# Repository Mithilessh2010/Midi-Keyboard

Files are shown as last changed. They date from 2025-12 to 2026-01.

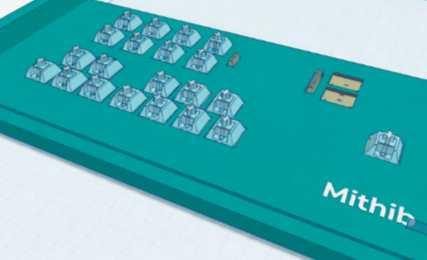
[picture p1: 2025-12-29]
Assets/CAD.png

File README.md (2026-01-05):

# Project README

## Overview
This project uses a Raspberry Pi Pico along with several input and output components to create a custom electronics system. The system includes switches, rotary encoders, a slide potentiometer, and supporting parts like diodes and connectors. The goal is to read user inputs and process them using the microcontroller.

## FINAL CAD WITH ASSEMBLED PARTS


## RENDER
Render

## SCHEMATICS
Schematics

## PCB
PCB

## CASE
CAD

## Bill of Materials (BOM)
| Component | Quantity | Price ($)  | Source |
| --- | --- | --- | --- |
| Cherry MX Blue Switch | 1 | 2.00 | [AliExpress](https://www.aliexpress.com/item/1005006255961111.html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) |
| Cherry MX Red Switch | 20 | 13.00 | [AliExpress](https://www.aliexpress.com/item/1005006255961111.html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) |
| S37735R Screen | 1 | N/A | Included in kit |
| 1N4148 Diode | 22 | N/A | Included in kit |
| Orpheus Pico | 1 | N/A | Included in kit |
| PCM5100 DAC | 1 | N/A | Included in kit |
| EC11 Rotary Encoder | 2 | N/A | Included in kit |
| M3 18 mm Screw | 4 | 1.06 | [BambuLab](https://us.store.bambulab.com/products/m3-button-head-cap-machine-screws-bhcs?id=42338644951176) |
| M3 4 mm Screw | 4 | 1.06 | [BambuLab](https://us.store.bambulab.com/products/m3-button-head-cap-machine-screws-bhcs?id=42338644721800) |
| M2 5 mm Screw | 2 | 1.02 | [BambuLab](https://us.store.bambulab.com/products/m2-button-head-cap-machine-screws-bhcs?id=42328200577160) |
| Slide Potentiometer | 1 | Included | [Adafruit](https://www.adafruit.com/product/4219) |
| ADS ADC Module | 1 | Included | [Adafruit](https://www.adafruit.com/product/1083) |
| **Adafruit Parts Total** | — | **34.30**  | [Adafruit](https://www.adafruit.com/) |
| **JLCPCB (PCB + Assembly)** | — | **52.46**  | [JLCPCB](https://jlcpcb.com/) |
| **BambuLab Shipping** | — | **6.00** | [BambuLab](https://us.store.bambulab.com/) |
| **TOTAL COST (All Parts)**  | — | **110.90** | — |

## How It Works
- The Raspberry Pi Pico acts as the main controller.
- Switches and encoders are used for user input.
- The slide potentiometer provides analog input.
- The ADC and DAC handle analog-to-digital and digital-to-analog conversion.
- Diodes help protect and control signal flow.

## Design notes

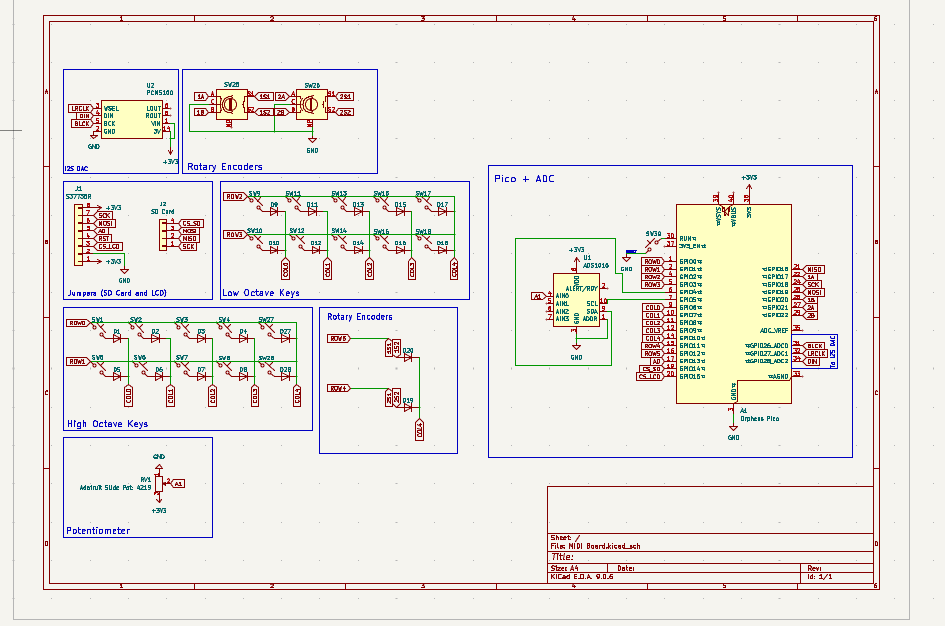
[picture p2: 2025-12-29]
Assets/Schematics.png

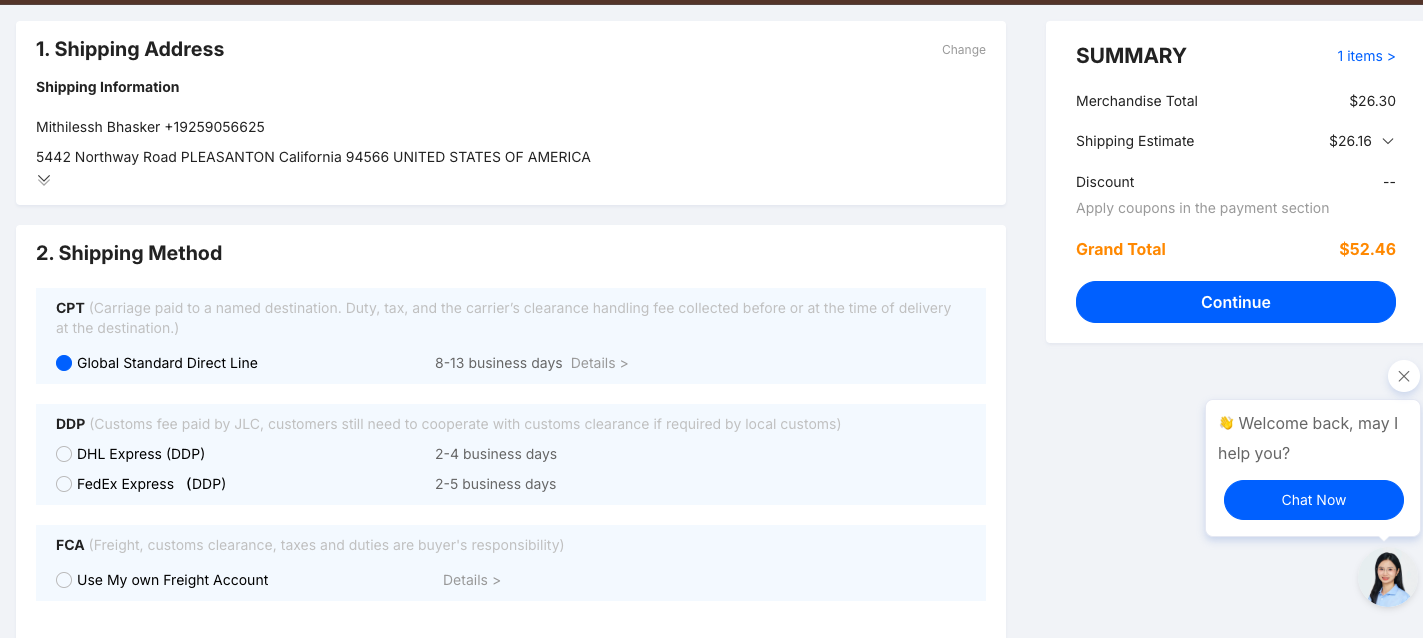
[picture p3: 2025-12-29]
Assets/JLCPCB.png

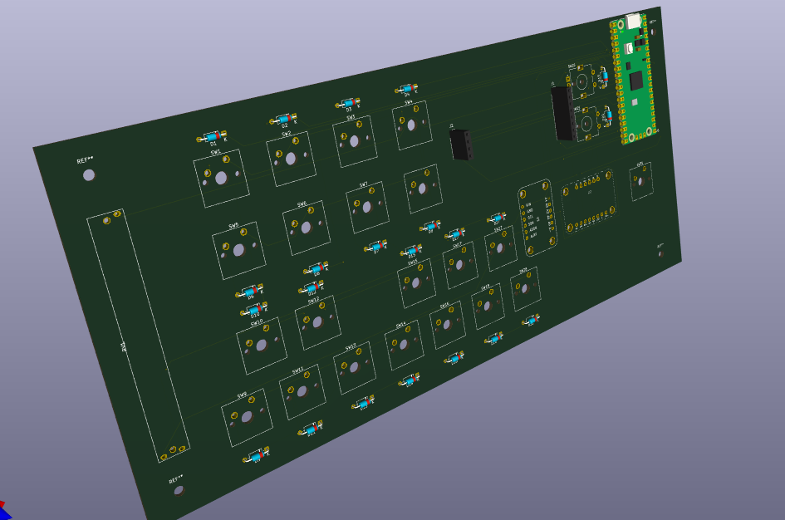
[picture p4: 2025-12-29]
Assets/Render.png

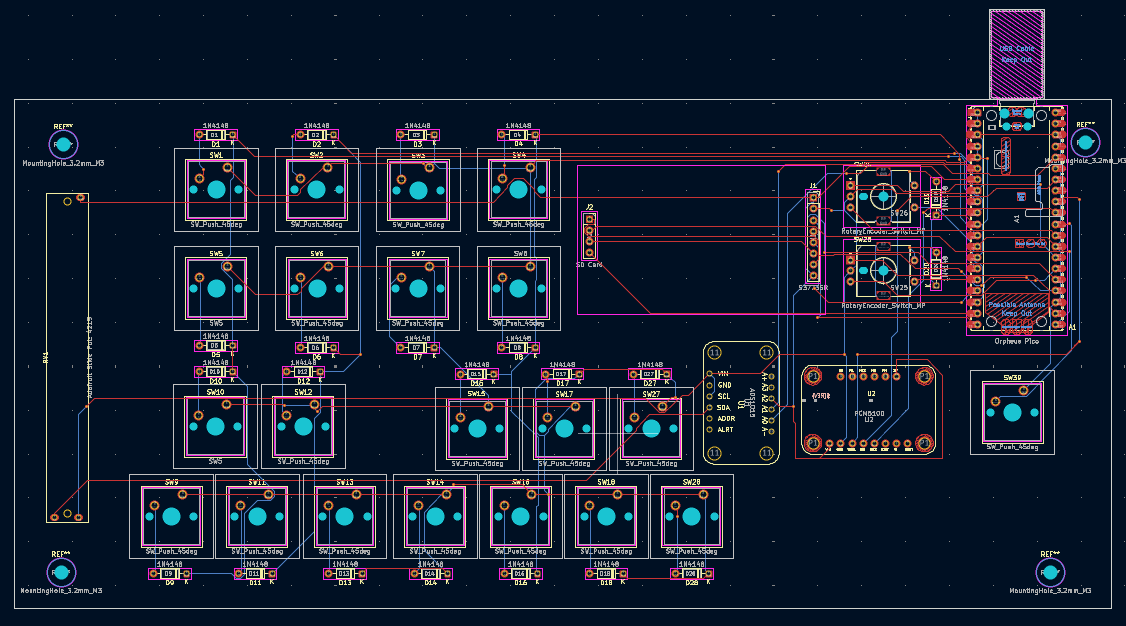
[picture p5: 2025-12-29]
Assets/PCB.png

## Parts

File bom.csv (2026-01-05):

Component | Quantity | Price ($) | Source
Cherry MX Blue Switch | 1 | 2.00 | https://www.aliexpress.com/item/1005006255961111.html?mp=1
Cherry MX Red Switch | 20 | 13.00 | https://www.aliexpress.com/item/1005006255961111.html?mp=1
S37735R Screen | 1 | N/A | Included in kit
1N4148 Diode | 22 | N/A | Included in kit
Orpheus Pico | 1 | N/A | Included in kit
PCM5100 DAC | 1 | N/A | Included in kit
EC11 Rotary Encoder | 2 | N/A | Included in kit
M3 18 mm Screw | 4 | 1.06 | https://us.store.bambulab.com/products/m3-button-head-cap-machine-screws-bhcs?id=42338644951176
M3 4 mm Screw | 4 | 1.06 | https://us.store.bambulab.com/products/m3-button-head-cap-machine-screws-bhcs?id=42338644721800
M2 5 mm Screw | 2 | 1.02 | https://us.store.bambulab.com/products/m2-button-head-cap-machine-screws-bhcs?id=42328200577160
Slide Potentiometer | 1 | Included | https://www.adafruit.com/product/4219
ADS ADC Module | 1 | Included | https://www.adafruit.com/product/1083
Adafruit Parts Total | — | 34.30 | https://www.adafruit.com/
JLCPCB (PCB + Assembly) | — | 52.46 | https://jlcpcb.com/
BambuLab Shipping | — | 6.00 | https://us.store.bambulab.com/
TOTAL COST (All Parts) | — | 110.90

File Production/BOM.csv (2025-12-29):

Id | Designator | Footprint | Quantity | Designation | Supplier and ref
1 | SW4,SW14,SW6,SW11,SW9,SW28,SW15,SW12,SW18,SW3,SW1,SW2,SW13,SW16,SW27,SW8,SW39,SW7,SW17 | SW_Cherry_MX_1.00u_PCB | 19 | SW_Push_45deg
2 | D7,D11,D6,D27,D2,D13,D1,D15,D20,D19,D17,D4,D16,D18,D5,D9,D3,D28,D14,D12,D8,D10 | D_DO-35_SOD27_P7.62mm_Horizontal | 22 | 1N4148
3 | J1 | PinSocket_1x08_P2.54mm_Vertical | 1 | S37735R
4 | SW10,SW5 | SW_Cherry_MX_1.00u_PCB | 2 | SW5
5 | U1 | Adafruit_ADS1115 | 1 | ADS1015
6 | SW25,SW26 | RotaryEncoder_Alps_EC11E-Switch_Vertical_H20mm_MountingHoles | 2 | RotaryEncoder_Switch_MP
7 | RV1 | Slide_Pot_75mm_Adafruit4219_fixed | 1 | Adafruit Slide Pot: 4219
8 | J2 | PinSocket_1x04_P2.54mm_Vertical | 1 | SD Card
9 | A1 | RaspberryPi_Pico_Common_Unspecified | 1 | Orpheus Pico
10 | U2 | PCM5100 I2S DAC | 1 | PCM5100

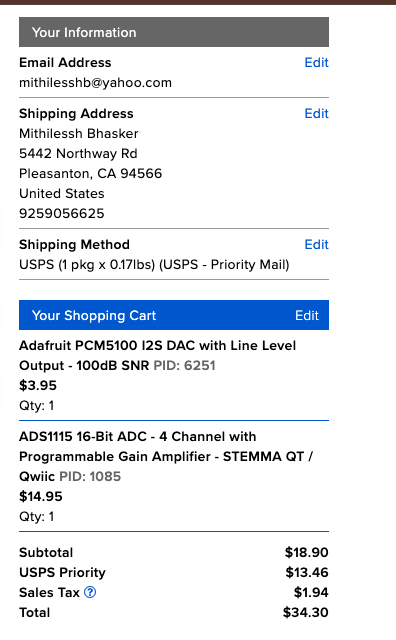
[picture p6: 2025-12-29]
Assets/Extra Parts Cost.png

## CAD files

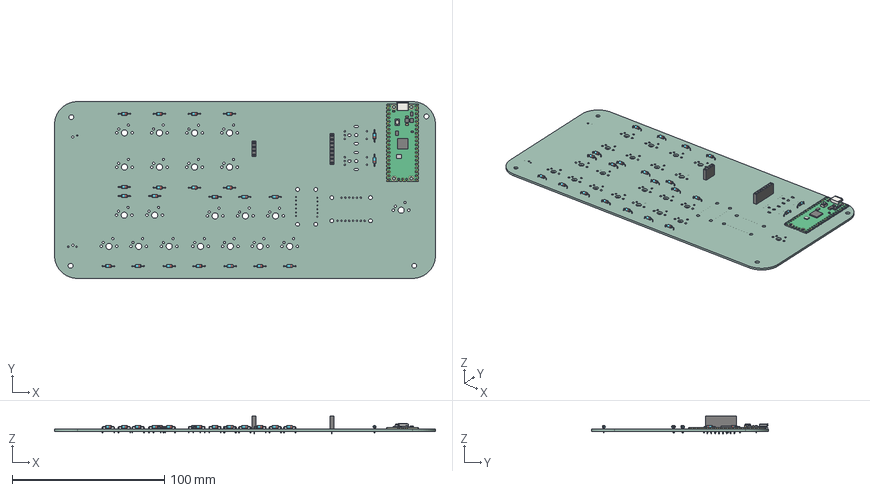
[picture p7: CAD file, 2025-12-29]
CAD/MIDI Board-PCB.step
250.0 x 116.0 x 11.6 mm
D_DO-35_SOD27_P7.62mm_Horizontal x 22
PinSocket_1x08_P2.54mm_Vertical
PinSocket_1x04_P2.54mm_Vertical
RaspberryPi_Pico_Module_KiCad
MIDI Board_PCB

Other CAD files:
CAD/pcb-with-case.stl

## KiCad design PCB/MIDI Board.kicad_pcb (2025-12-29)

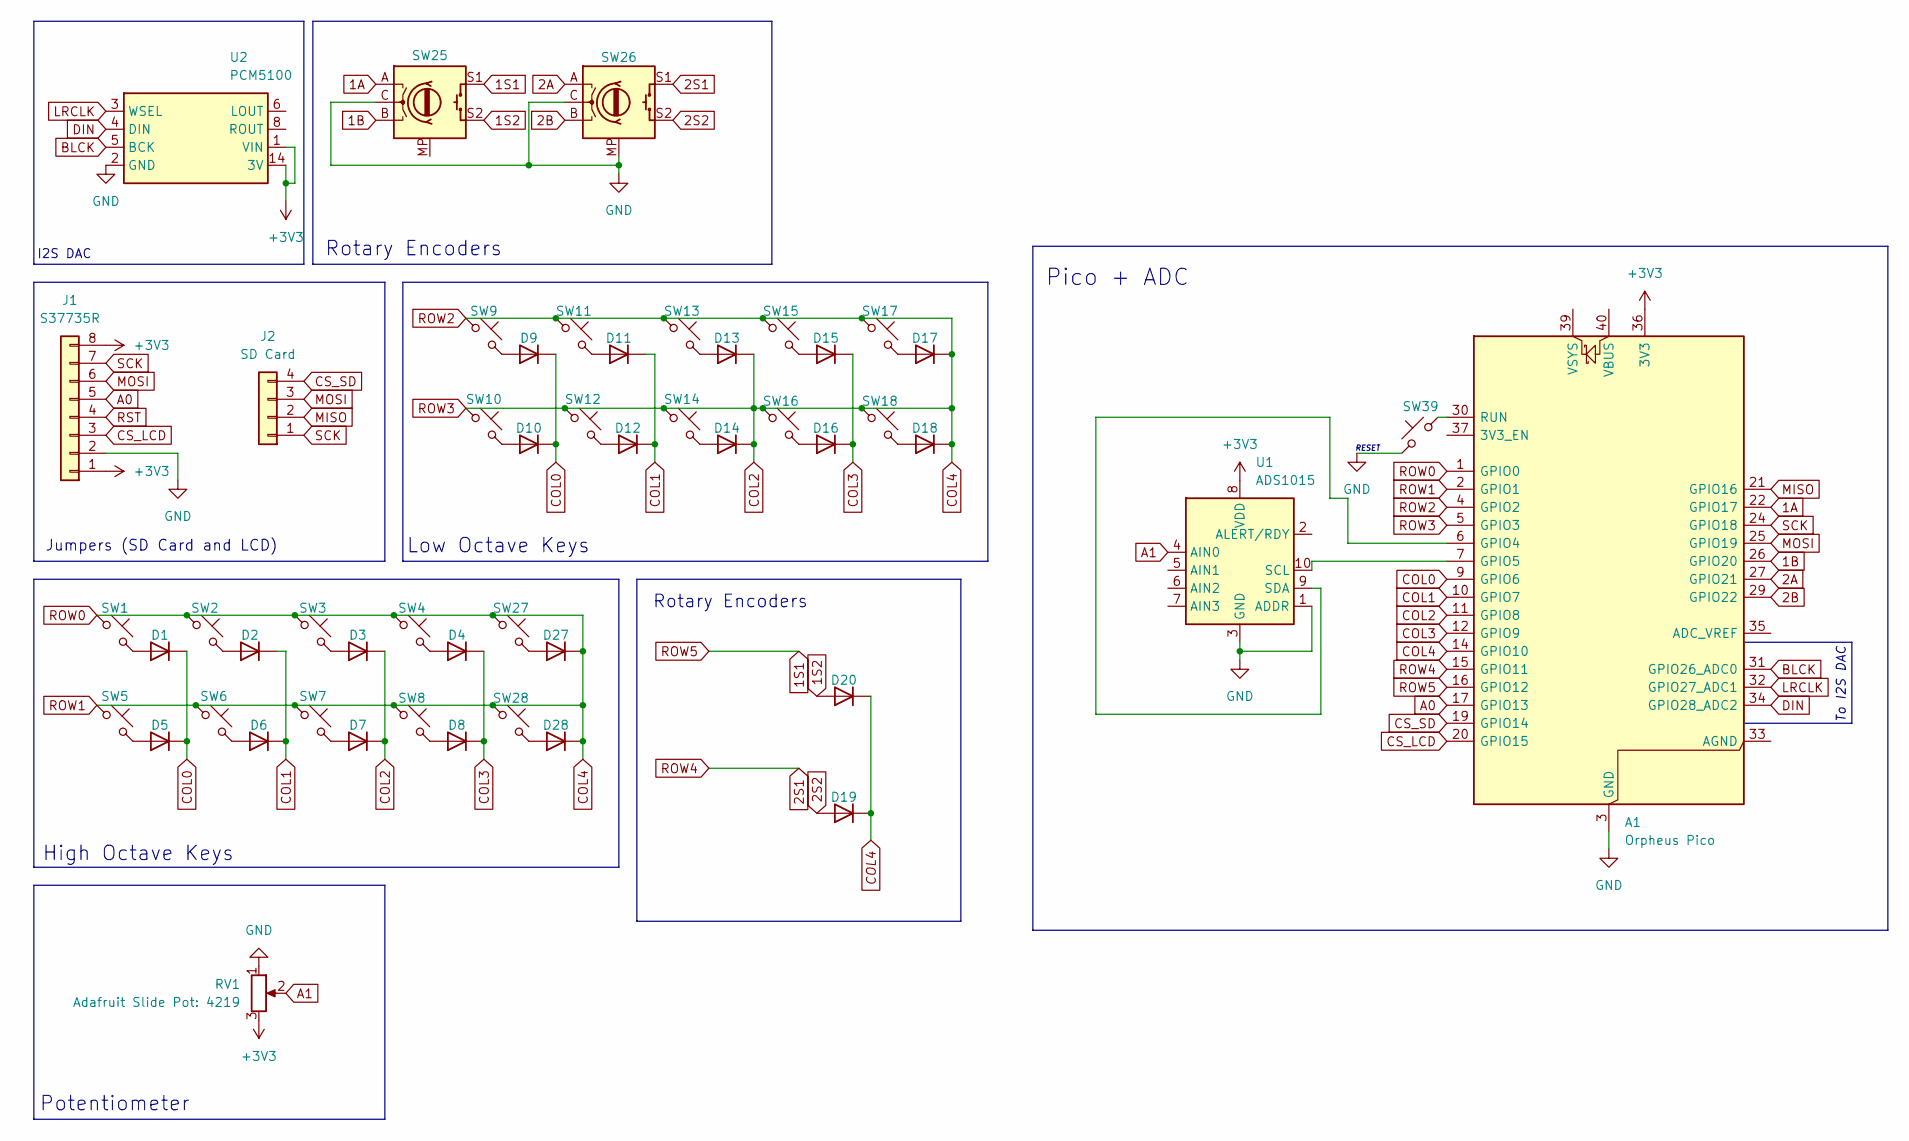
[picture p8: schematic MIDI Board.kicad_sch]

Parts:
A1: Orpheus Pico; RaspberryPi_Pico_Common_Unspecified
D1, D2, D3, D4, D5, D6, D7, D8, D9, D10, D11, D12, D13, D14, D15, D16, D17, D18, D19, D20, D27, D28: 1N4148; D_DO-35_SOD27_P7.62mm_Horizontal
J1: S37735R; PinSocket_1x08_P2.54mm_Vertical
J2: SD Card; PinSocket_1x04_P2.54mm_Vertical
RV1: Adafruit Slide Pot: 4219; Slide_Pot_75mm_Adafruit4219_fixed
SW1, SW2, SW3, SW4, SW6, SW7, SW8, SW9, SW11, SW12, SW13, SW14, SW15, SW16, SW17, SW18, SW27, SW28, SW39: SW_Push_45deg; SW_Cherry_MX_1.00u_PCB
SW5, SW10: SW5; SW_Cherry_MX_1.00u_PCB
SW25, SW26: RotaryEncoder_Switch_MP; RotaryEncoder_Alps_EC11E-Switch_Vertical_H20mm_MountingHoles
U1: ADS1015; Adafruit_ADS1115
U2: PCM5100; PCM5100 I2S DAC

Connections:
1A: A1.22 (GPIO17), SW25.A
1B: A1.26 (GPIO20), SW25.B
1S1: A1.16 (GPIO12), SW25.S1
1S2: D20.2 (A), SW25.S2
2A: A1.27 (GPIO21), SW26.A
2B: A1.29 (GPIO22), SW26.B
2S1: A1.15 (GPIO11), SW26.S1
2S2: D19.2 (A), SW26.S2
+3V3: A1.36 (3V3), J1.1, J1.8, RV1.3, U1.8 (VDD), U2.1 (VIN), U2.14 (3V)
A0: A1.17 (GPIO13), J1.5
A1: RV1.2, U1.4 (AIN0)
BLCK: A1.31 (GPIO26_ADC0), U2.5 (BCK)
COL0: A1.9 (GPIO6), D1.1 (K), D5.1 (K), D9.1 (K), D10.1 (K)
COL1: A1.10 (GPIO7), D2.1 (K), D6.1 (K), D11.1 (K), D12.1 (K)
COL2: A1.1 (GPIO0), A1.2 (GPIO1), A1.4 (GPIO2), A1.5 (GPIO3), A1.11 (GPIO8), A1.14 (GPIO10), D3.1 (K), D7.1 (K), D13.1 (K), D14.1 (K), D17.1 (K), D18.1 (K), D19.1 (K), D20.1 (K), D27.1 (K), D28.1 (K), SW1.1, SW2.1, SW3.1, SW4.1, SW5.1, SW6.1, SW7.1, SW8.1, SW9.1, SW10.1, SW11.1, SW12.1, SW13.1, SW14.1, SW15.1, SW16.1, SW17.1, SW18.1, SW27.1, SW28.1
COL3: A1.12 (GPIO9), D4.1 (K), D8.1 (K), D15.1 (K), D16.1 (K)
CS_LCD: A1.20 (GPIO15), J1.3
CS_SD: A1.19 (GPIO14), J2.4
DIN: A1.34 (GPIO28_ADC2), U2.4 (DIN)
GND: A1.3 (GND), A1.8 (GND), A1.13 (GND), A1.18 (GND), A1.23 (GND), A1.28 (GND), A1.38 (GND), J1.2, RV1.1, SW25.C, SW26.C, SW26.MP, SW39.1, U1.1 (ADDR), U1.3 (GND), U2.2 (GND)
LRCLK: A1.32 (GPIO27_ADC1), U2.3 (WSEL)
MISO: A1.21 (GPIO16), J2.2
MOSI: A1.25 (GPIO19), J1.6, J2.3
unnamed: A1.6 (GPIO4), U1.9 (SDA)
unnamed: A1.7 (GPIO5), U1.10 (SCL)
unnamed: A1.30 (RUN), SW39.2
unnamed: D1.2 (A), SW1.2
unnamed: D2.2 (A), SW2.2
unnamed: D3.2 (A), SW3.2
unnamed: D4.2 (A), SW4.2
unnamed: D5.2 (A), SW5.2
unnamed: D6.2 (A), SW6.2
unnamed: D7.2 (A), SW7.2
unnamed: D8.2 (A), SW8.2
unnamed: D9.2 (A), SW9.2
unnamed: D10.2 (A), SW10.2
unnamed: D11.2 (A), SW11.2
unnamed: D12.2 (A), SW12.2
unnamed: D13.2 (A), SW13.2
unnamed: D14.2 (A), SW14.2
unnamed: D15.2 (A), SW15.2
unnamed: D16.2 (A), SW16.2
unnamed: D17.2 (A), SW17.2
unnamed: D18.2 (A), SW18.2
unnamed: D27.2 (A), SW27.2
unnamed: D28.2 (A), SW28.2
RST: J1.4
SCK: A1.24 (GPIO18), J1.7, J2.1

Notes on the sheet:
I2S DAC
To I2S DAC
Potentiometer
Rotary Encoders
Jumpers (SD Card and LCD)
Low Octave Keys
High Octave Keys
RESET
Pico + ADC

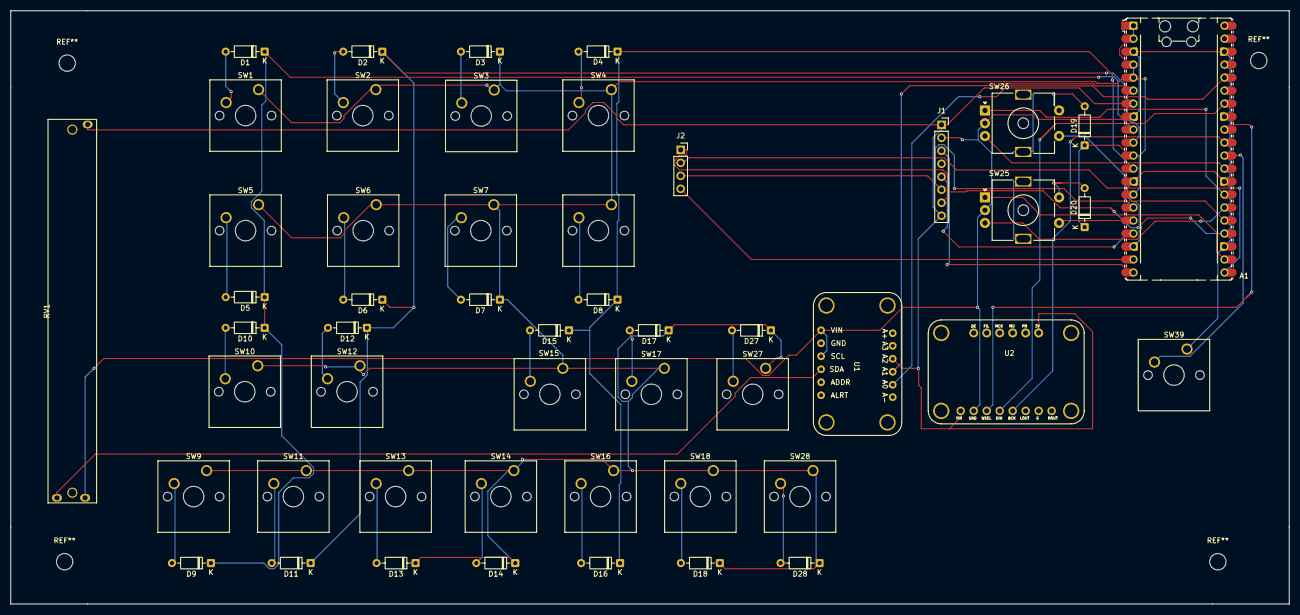
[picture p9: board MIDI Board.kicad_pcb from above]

Board: 2 copper layers, 250.0 x 116.0 mm, 51 parts (0 on the bottom side), 47 nets.

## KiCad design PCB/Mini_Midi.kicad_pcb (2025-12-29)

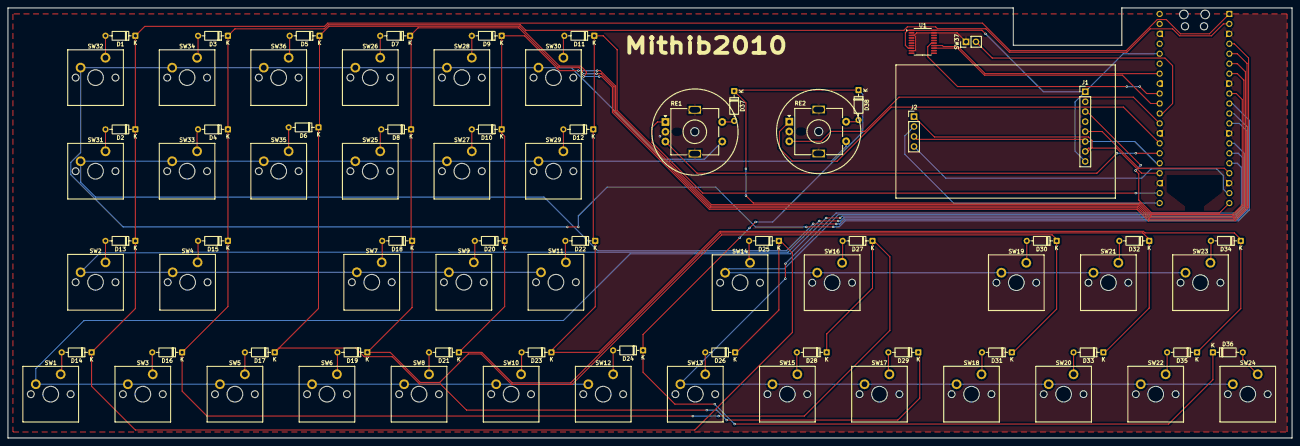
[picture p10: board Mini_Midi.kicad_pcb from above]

Board: 2 copper layers, 327.7 x 109.7 mm, 81 parts (1 on the bottom side), 67 nets.

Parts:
A1: Orpheus_Pico; RaspberryPi_Pico_Common_Unspecified
D1, D2, D3, D4, D5, D6, D7, D8, D9, D10, D11, D12, D13, D14, D15, D16, D17, D18, D19, D20, D21, D22, D23, D24, D25, D26, D27, D28, D29, D30, D31, D32, D33, D34, D35, D36, D37, D38: 1N4148; D_DO-35_SOD27_P7.62mm_Horizontal
J1: ST7735R; PinHeader_1x08_P2.54mm_Vertical
J2: SD Card; PinHeader_1x04_P2.54mm_Vertical
RE1, RE2: RotaryEncoder_Switch_MP; RotaryEncoder_Alps_EC11E-Switch_Vertical_H20mm_MountingHoles
SW1, SW2, SW3, SW4, SW5, SW6, SW7, SW8, SW9, SW10, SW11, SW12, SW13, SW14, SW15, SW16, SW17, SW18, SW19, SW20, SW21, SW22, SW23, SW24, SW25, SW26, SW27, SW28, SW29, SW30, SW31, SW32, SW33, SW34, SW35, SW36: SW_Push_45deg; MX_PCB_1.00u
SW37: SW_SPST; PinHeader_1x02_P2.54mm_Vertical
U1: PCM5100; TSSOP-20_4.4x6.5mm_P0.65mm

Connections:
1A: A1.22 (GPIO17), RE1.A
1B: A1.26 (GPIO20), RE1.B
1S1: A1.10 (GPIO7), RE1.S1, SW26.1, SW28.1, SW30.1, SW32.1, SW34.1, SW36.1
1S2: D37.2 (A), RE1.S2
2A: A1.27 (GPIO21), RE2.A
2B: A1.29 (GPIO22), RE2.B
2S1: A1.11 (GPIO8), RE2.S1, SW25.1, SW27.1, SW29.1, SW31.1, SW33.1, SW35.1
2S2: D38.2 (A), RE2.S2
+3V3: A1.36 (3V3), J1.1, J1.8, U1.1 (CPVDD), U1.8 (AVDD), U1.20 (DVDD)
A0: A1.17 (GPIO13), J1.5
BCK: A1.31 (GPIO26_ADC0), U1.13 (BCK)
COL0: A1.1 (GPIO0), D1.1 (K), D2.1 (K), D13.1 (K), D14.1 (K), D25.1 (K), D26.1 (K)
COL1: A1.2 (GPIO1), D3.1 (K), D4.1 (K), D15.1 (K), D16.1 (K), D27.1 (K), D28.1 (K)
COL2: A1.4 (GPIO2), D5.1 (K), D6.1 (K), D17.1 (K), D29.1 (K)
COL3: A1.5 (GPIO3), D7.1 (K), D8.1 (K), D18.1 (K), D19.1 (K), D30.1 (K), D31.1 (K)
COL4: A1.6 (GPIO4), D9.1 (K), D10.1 (K), D20.1 (K), D21.1 (K), D32.1 (K), D33.1 (K)
COL5: A1.7 (GPIO5), D11.1 (K), D12.1 (K), D22.1 (K), D23.1 (K), D34.1 (K), D35.1 (K)
COL6: A1.9 (GPIO6), D24.1 (K), D36.1 (K), D37.1 (K), D38.1 (K)
CS_LCD: A1.20 (GPIO15), J1.3
CS_SD: A1.19 (GPIO14), J2.4
DIN: A1.34 (GPIO28_ADC2), U1.14 (DIN)
GND: A1.3 (GND), A1.8 (GND), A1.13 (GND), A1.18 (GND), A1.23 (GND), A1.28 (GND), A1.38 (GND), J1.2, RE1.C, RE1.MP, RE2.C, RE2.MP, SW37.1 (A), U1.3 (CPGND), U1.9 (AGND), U1.19 (DGND)
LRCK: A1.32 (GPIO27_ADC1), U1.15 (LRCK)
MISO: A1.21 (GPIO16), J2.2
MOSI: A1.25 (GPIO19), J1.6, J2.3
unnamed: A1.30 (RUN), SW37.2 (B)
unnamed: D1.2 (A), SW32.2
unnamed: D2.2 (A), SW31.2
unnamed: D3.2 (A), SW34.2
unnamed: D4.2 (A), SW33.2
unnamed: D5.2 (A), SW36.2
unnamed: D6.2 (A), SW35.2
unnamed: D7.2 (A), SW26.2
unnamed: D8.2 (A), SW25.2
unnamed: D9.2 (A), SW28.2
unnamed: D10.2 (A), SW27.2
unnamed: D11.2 (A), SW30.2
unnamed: D12.2 (A), SW29.2
unnamed: D13.2 (A), SW2.2
unnamed: D14.2 (A), SW1.2
unnamed: D15.2 (A), SW4.2
unnamed: D16.2 (A), SW3.2
unnamed: D17.2 (A), SW5.2
unnamed: D18.2 (A), SW7.2
unnamed: D19.2 (A), SW6.2
unnamed: D20.2 (A), SW9.2
unnamed: D21.2 (A), SW8.2
unnamed: D22.2 (A), SW11.2
unnamed: D23.2 (A), SW10.2
unnamed: D24.2 (A), SW12.2
unnamed: D25.2 (A), SW14.2
unnamed: D26.2 (A), SW13.2
unnamed: D27.2 (A), SW16.2
unnamed: D28.2 (A), SW15.2
unnamed: D29.2 (A), SW17.2
unnamed: D30.2 (A), SW19.2
unnamed: D31.2 (A), SW18.2
unnamed: D32.2 (A), SW21.2
unnamed: D33.2 (A), SW20.2
unnamed: D34.2 (A), SW23.2
unnamed: D35.2 (A), SW22.2
unnamed: D36.2 (A), SW24.2
ROW2: A1.12 (GPIO9), SW2.1, SW4.1, SW7.1, SW9.1, SW11.1
ROW3: A1.14 (GPIO10), SW1.1, SW3.1, SW5.1, SW6.1, SW8.1, SW10.1, SW12.1
ROW4: A1.15 (GPIO11), SW14.1, SW16.1, SW19.1, SW21.1, SW23.1
ROW5: A1.16 (GPIO12), SW13.1, SW15.1, SW17.1, SW18.1, SW20.1, SW22.1, SW24.1
SCK: A1.24 (GPIO18), J1.7, J2.1

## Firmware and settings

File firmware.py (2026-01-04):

import time
import board
import keypad
import rotaryio
import displayio
import busio
import terminalio
import audiobusio
import audiocore
import usb_midi
import adafruit_midi

from fourwire import FourWire
from adafruit_display_text import label
from adafruit_st7735r import ST7735R
from adafruit_midi.note_on import NoteOn
from adafruit_midi.note_off import NoteOff

rows = [board.GP0, board.GP1, board.GP2]
cols = [board.GP3, board.GP4, board.GP5]

matrix = keypad.KeyMatrix(
    row_pins=rows,
    column_pins=cols,
    columns_to_anodes=True
)

encoder = rotaryio.IncrementalEncoder(board.GP6, board.GP7)
last_enc_pos = encoder.position

displayio.release_displays()

spi = busio.SPI(clock=board.GP10, MOSI=board.GP11)
display_bus = FourWire(
    spi,
    command=board.GP12,
    chip_select=board.GP13,
    reset=board.GP14
)

display = ST7735R(
    display_bus,
    width=128,
    height=160,
    rotation=90
)

splash = displayio.Group()
display.root_group = splash

text_label = label.Label(
    terminalio.FONT,
    text="Mini MIDI Magic",
    color=0xFFFFFF,
    x=10,
    y=20
)

splash.append(text_label)

dac = audiobusio.I2SOut(
    bit_clock=board.GP18,
    word_select=board.GP19,
    data=board.GP20
)

try:
    wav_file = open("sound.wav", "rb")
    wav = audiocore.WaveFile(wav_file)
    dac.play(wav)
    while dac.playing:
        pass
except OSError:
    pass

midi = adafruit_midi.MIDI(
    midi_in=usb_midi.ports[0],
    midi_out=usb_midi.ports[1],
    in_channel=0,
    out_channel=0
)

while True:
    event = matrix.events.get()
    if event:
        note = 60 + event.key_number
        if event.pressed:
            midi.send(NoteOn(note, 127))
        else:
            midi.send(NoteOff(note, 0))

    pos = encoder.position
    if pos != last_enc_pos:
        last_enc_pos = pos

    time.sleep(0.01)

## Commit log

2025-12-29 All files
    [BOM.csv, MIDI Board-PCB.step, MIDI Board.kicad_pcb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]
2026-01-04 Revise BOM with component prices and sources
    Updated the Bill of Materials section to include pricing and sources for components.
2026-01-04 Update Bill of Materials in README
2026-01-05 Add bill of materials (bom.csv) for components
    [bom.csv]
2026-01-05 Update README with CAD and render images
    Added final CAD image and render to README.
2026-01-05 Replace image in README with updated CAD
    Updated the image in the 'FINAL CAD WITH ASSEMBLED PARTS' section.
